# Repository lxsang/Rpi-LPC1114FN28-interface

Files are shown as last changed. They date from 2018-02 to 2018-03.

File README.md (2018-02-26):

# Rpi-LPC1114FN28-interface

This is a hobby project for an embedded application.  The point is that the Pi  is connected to a circuit based on the LPC1114FN28, in which, the ARM cortex M0 chip is used to collect sensor datas (IR sensor, sonar sensor, etc.) and control some motors using an IC controller. The Pi talks to the LPC1114FN28 via a serial connection (UART or SPI), and takes care of some high level calculations based on the datas provided by the LPC chip, it then can analyse the environment's context and send commands to the slave (ARM) chip for some control. For this prject, i decide to design my own PCB for the interface and write a firmware/middleware for  the interface.

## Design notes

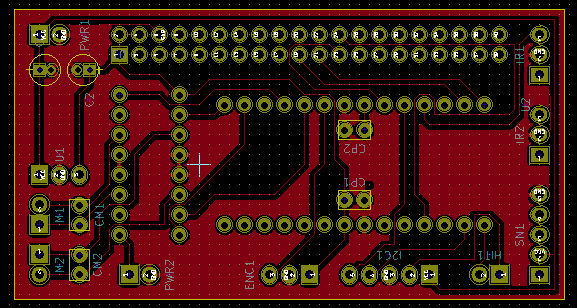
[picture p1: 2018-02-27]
schematic/images/pcb-front.png

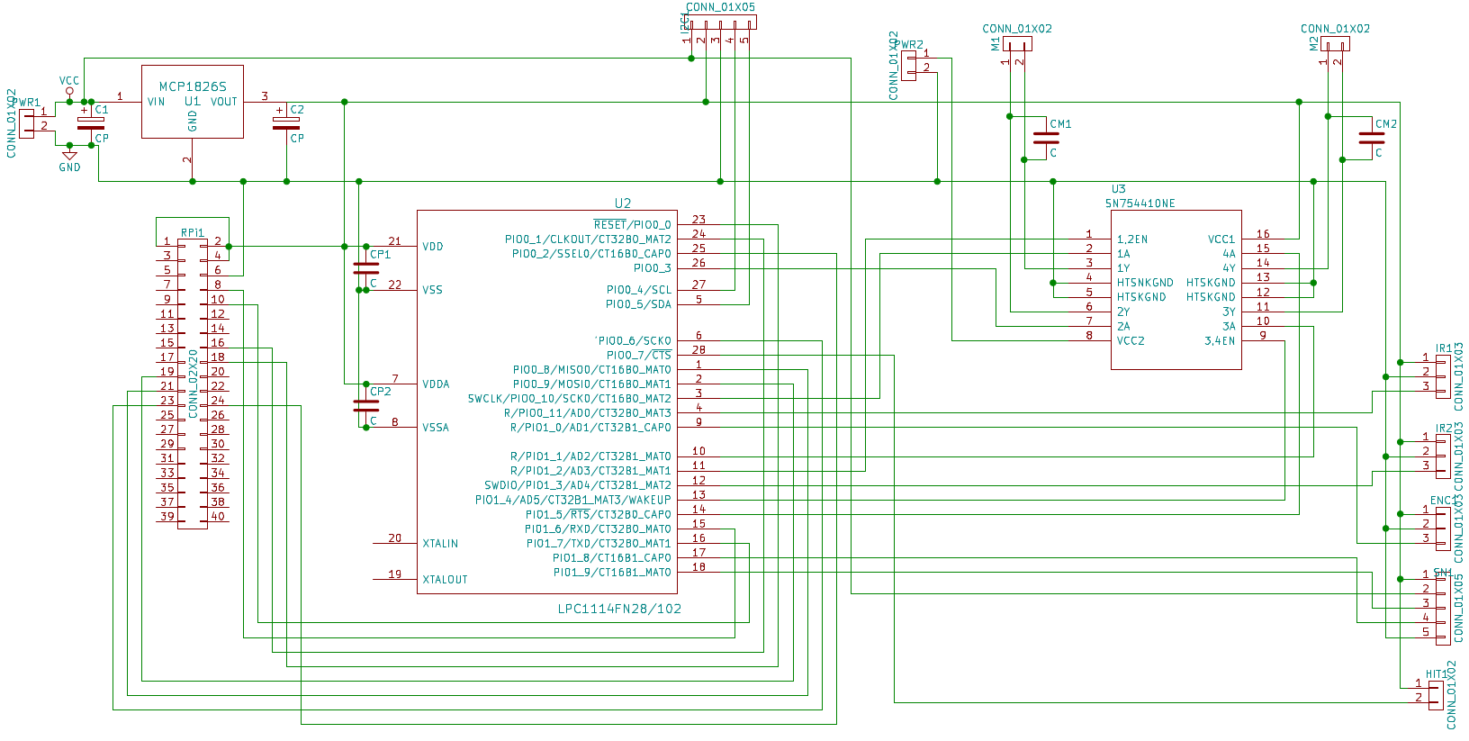
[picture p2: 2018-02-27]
schematic/images/schematic.png

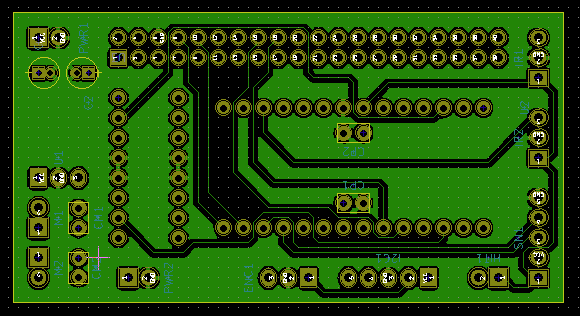
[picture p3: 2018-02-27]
schematic/images/pcb-back.png

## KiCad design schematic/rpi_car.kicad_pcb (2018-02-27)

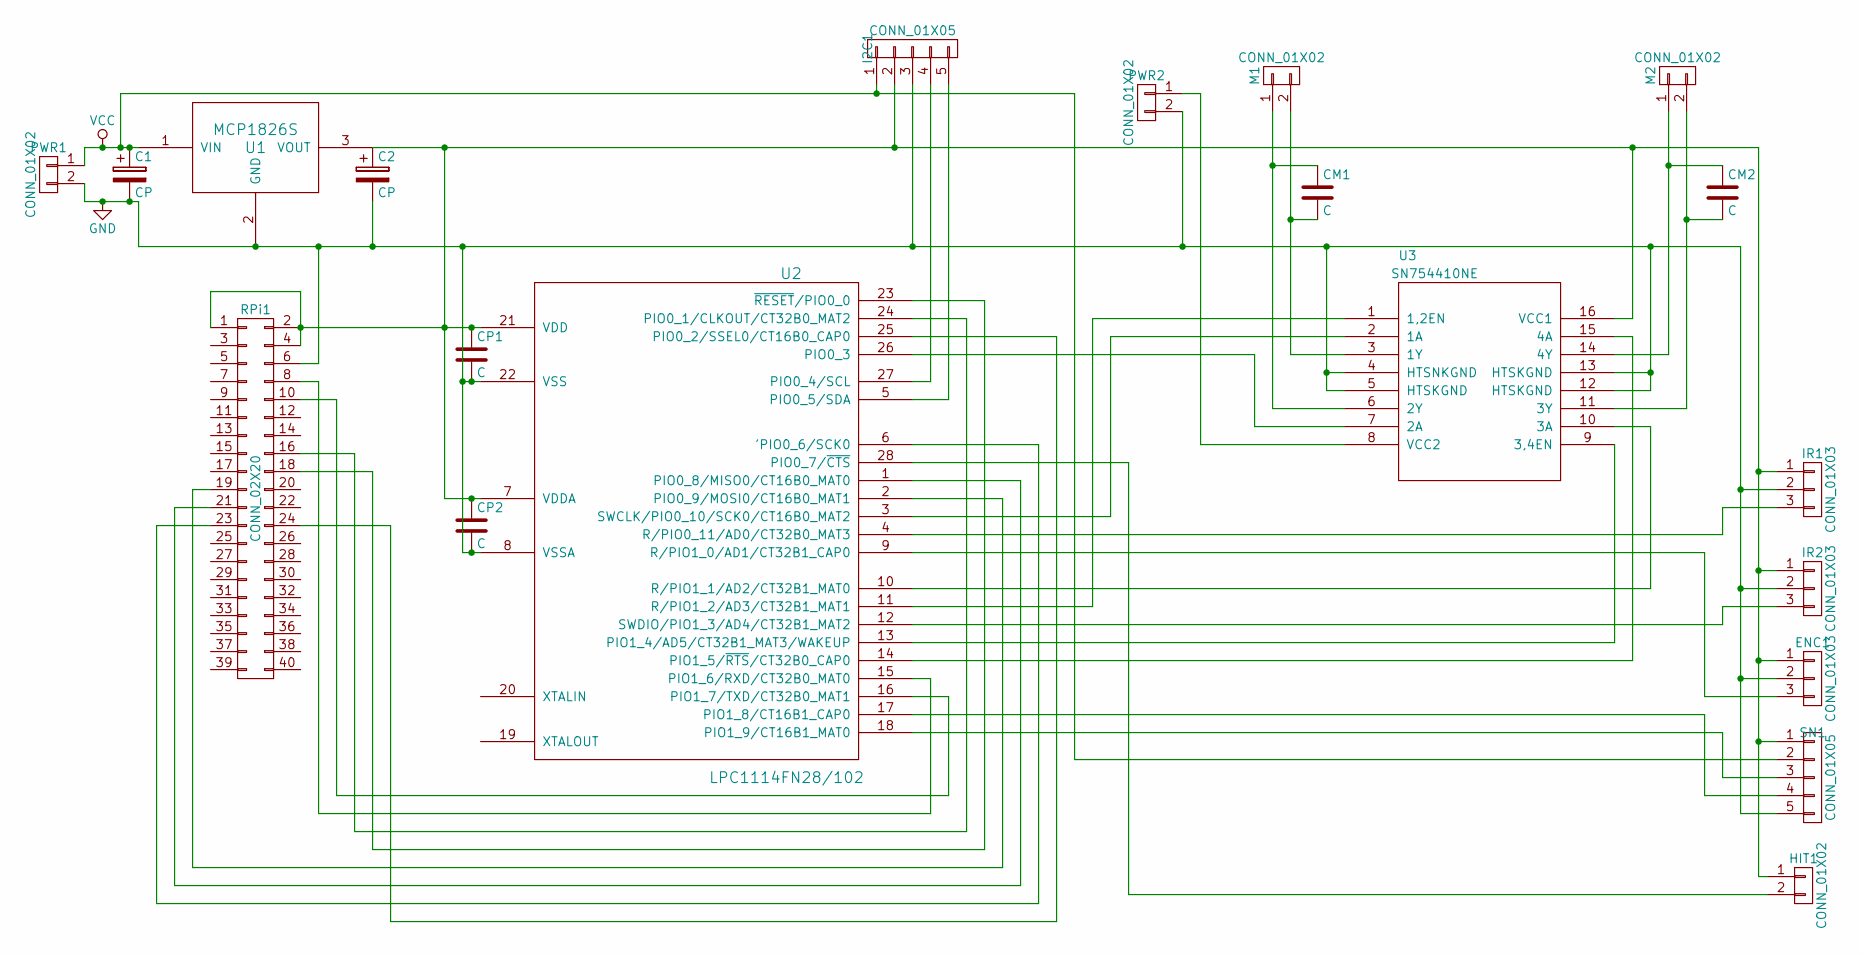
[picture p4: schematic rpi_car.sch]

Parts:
C1, C2: CP; CP_Radial_D4.0mm_P1.50mm
CM1, CM2: C; C_Rect_L4.0mm_W2.5mm_P2.50mm
CP1, CP2: C; C_Rect_L4.0mm_W2.5mm_P2.50mm
ENC1: CONN_01X03; Pin_Header_Straight_1x03
HIT1: CONN_01X02; Pin_Header_Straight_1x02
I2C1: CONN_01X05; Pin_Header_Straight_1x05
IR1, IR2: CONN_01X03; Pin_Header_Straight_1x03
M1, M2: CONN_01X02; Pin_Header_Straight_1x02
PWR1, PWR2: CONN_01X02; Pin_Header_Straight_1x02
RPi1: CONN_02X20; Pin_Header_Straight_2x20
SN1: CONN_01X05; Pin_Header_Straight_1x05
U1: MCP1826S; Pin_Header_Straight_1x03
U2: LPC1114FN28/102; DIP-28_W15.24mm
U3: SN754410NE; DIP-16_W7.62mm

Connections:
GND: C1.2, C2.2, CP1.2, CP2.2, ENC1.2, I2C1.3, IR1.2, IR2.2, PWR1.2, PWR2.2, RPi1.6, SN1.5, U1.2 (GND), U2.8 (VSSA), U2.22 (VSS), U3.4 (HTSNKGND), U3.5 (HTSKGND), U3.12 (HTSKGND), U3.13 (HTSKGND)
unnamed: C2.1, CP1.1, CP2.1, ENC1.1, HIT1.1, I2C1.2, IR1.1, IR2.1, RPi1.1, RPi1.2, RPi1.4, SN1.1, U1.3 (VOUT), U2.7 (VDDA), U2.21 (VDD), U3.16 (VCC1)
unnamed: CM1.1, M1.1, U3.6 (2Y)
unnamed: CM1.2, M1.2, U3.3 (1Y)
unnamed: CM2.1, M2.1, U3.14 (4Y)
unnamed: CM2.2, M2.2, U3.11 (3Y)
unnamed: ENC1.3, U2.9 (R/PIO1_0/AD1/CT32B1_CAP0)
unnamed: HIT1.2, U2.28 (PIO0_7/~CTS)
unnamed: I2C1.4, U2.27 (PIO0_4/SCL)
unnamed: I2C1.5, U2.5 (PIO0_5/SDA)
unnamed: IR1.3, U2.4 (R/PIO0_11/AD0/CT32B0_MAT3)
unnamed: IR2.3, U2.12 (SWDIO/PIO1_3/AD4/CT32B1_MAT2)
unnamed: PWR2.1, U3.8 (VCC2)
unnamed: RPi1.8, U2.15 (PIO1_6/RXD/CT32B0_MAT0)
unnamed: RPi1.10, U2.16 (PIO1_7/TXD/CT32B0_MAT1)
unnamed: RPi1.16, U2.24 (PIO0_1/CLKOUT/CT32B0_MAT2)
unnamed: RPi1.18, U2.23 (~RESET~/PIO0_0)
unnamed: RPi1.19, U2.2 (PIO0_9/MOSI0/CT16B0_MAT1)
unnamed: RPi1.21, U2.1 (PIO0_8/MISO0/CT16B0_MAT0)
unnamed: RPi1.23, U2.6 ('PIO0_6/SCK0)
unnamed: RPi1.24, U2.25 (PIO0_2/SSEL0/CT16B0_CAP0)
unnamed: SN1.3, U2.18 (PIO1_9/CT16B1_MAT0)
unnamed: SN1.4, U2.17 (PIO1_8/CT16B1_CAP0)
unnamed: U2.3 (SWCLK/PIO0_10/SCK0/CT16B0_MAT2), U3.2 (1A)
unnamed: U2.10 (R/PIO1_1/AD2/CT32B1_MAT0), U3.10 (3A)
unnamed: U2.11 (R/PIO1_2/AD3/CT32B1_MAT1), U3.1 (1,2EN)
unnamed: U2.13 (PIO1_4/AD5/CT32B1_MAT3/WAKEUP), U3.9 (3,4EN)
unnamed: U2.14 (PIO1_5/~RTS~/CT32B0_CAP0), U3.15 (4A)
unnamed: U2.26 (PIO0_3), U3.7 (2A)
VCC: C1.1, I2C1.1, PWR1.1, SN1.2, U1.1 (VIN)

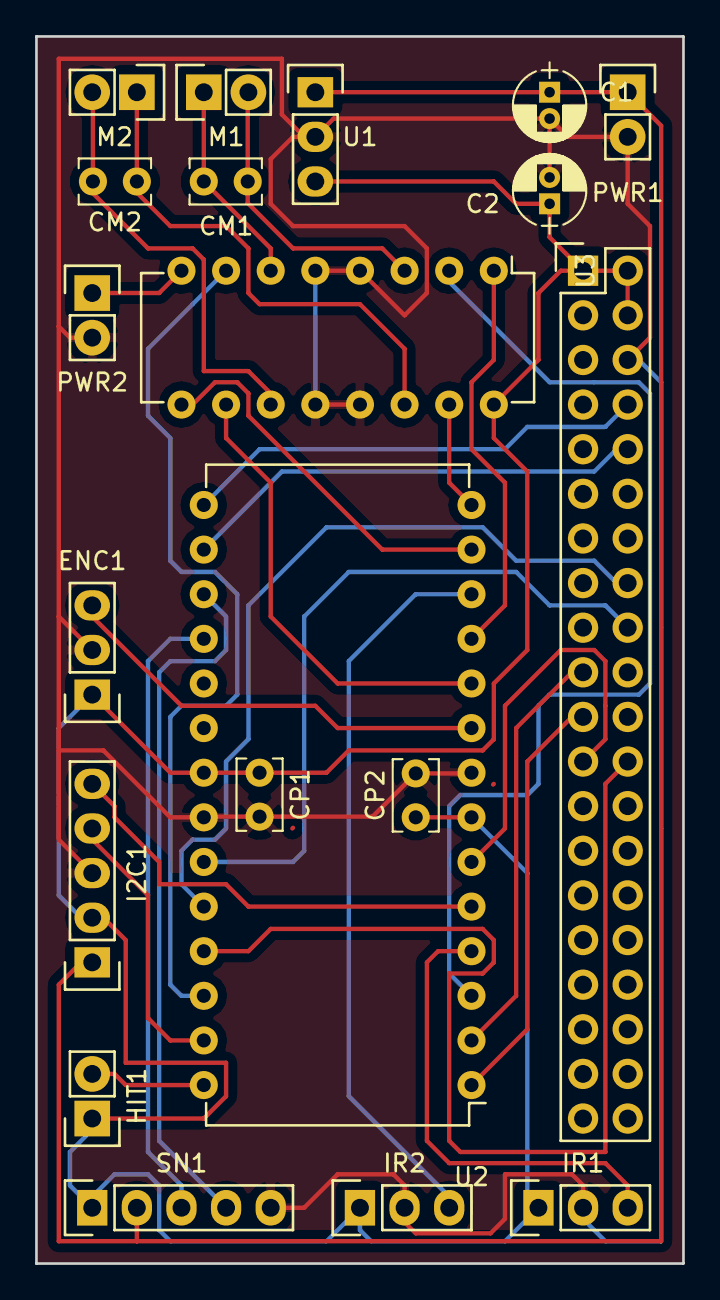
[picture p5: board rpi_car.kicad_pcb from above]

Board: 2 copper layers, 36.8 x 69.8 mm, 20 parts (0 on the bottom side), 30 nets.

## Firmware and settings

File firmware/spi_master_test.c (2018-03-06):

#include <stdint.h>
#include <unistd.h>
#include <stdio.h>
#include <stdlib.h>
#include <getopt.h>
#include <fcntl.h>
#include <sys/ioctl.h>
#include <linux/types.h>
#include <linux/spi/spidev.h>

#define ARRAY_SIZE(a) (sizeof(a) / sizeof((a)[0]))

static const char *device = "/dev/spidev0.0";
static uint8_t mode;
static uint8_t bits = 8;
static uint32_t speed = 500000;
static uint16_t delay = 110;

int spi_open()
{
    int ret;
    int fd = open(device, O_RDWR);
	if (fd < 0)
	{
		perror("can't open device \n");
		return -1;
	}
	/*
	 * spi mode
	 */
	ret = ioctl(fd, SPI_IOC_WR_MODE, &mode);
	if (ret == -1)
	{
	    perror("can't set spi mode \n");
	    return -1;
	}

	ret = ioctl(fd, SPI_IOC_RD_MODE, &mode);
	if (ret == -1)
	{
		perror("can't get spi mode \n");
		return -1;
	}
	/*
	 * bits per word
	 */
	ret = ioctl(fd, SPI_IOC_WR_BITS_PER_WORD, &bits);
	if (ret == -1)
	{
		perror("can't set bits per word \n");
		return -1;
	}

	ret = ioctl(fd, SPI_IOC_RD_BITS_PER_WORD, &bits);
	if (ret == -1)
	{
	    perror("can't get bits per word");
	    return -1;
	}
	/*
	 * max speed hz
	 */
	ret = ioctl(fd, SPI_IOC_WR_MAX_SPEED_HZ, &speed);
	if (ret == -1)
	{
	    perror("can't set max speed hz");
	    return -1;
	}
	ret = ioctl(fd, SPI_IOC_RD_MAX_SPEED_HZ, &speed);
	if (ret == -1)
	{
		perror("can't get max speed hz");
		return -1;
	}

	printf("spi mode: %d\n", mode);
	printf("bits per word: %d\n", bits);
	printf("max speed: %d Hz (%d KHz)\n", speed, speed/1000);
	
	return fd;
}

int spi_send_cmd(int fd, uint8_t cmd, uint8_t idx, uint8_t value)
{
    int ret;
    uint8_t tx[3]; 
    uint8_t rx[3] = {0, };
	struct spi_ioc_transfer tr = {
		.tx_buf = (unsigned long)tx,
		.rx_buf = (unsigned long)rx,
		.len = 3,
		.delay_usecs = delay,
		.speed_hz = speed,
		.bits_per_word = bits
	};
	tx[0] = cmd;
	tx[1] = idx;
	tx[2] = value;
	ret = ioctl(fd, SPI_IOC_MESSAGE(1), &tr);
    if (ret < 1)
    {
        perror("can't send spi message");
    	return -1;
    }
    //if(cmd == 255)
    // printf("RX %d %d %d \n", rx[0], rx[1], rx[2]);
    return (int) rx[0];
}

int spi_set(int fd,uint8_t idx, uint8_t v)
{
    return spi_send_cmd(fd,1, idx, v);
}

int spi_get(int fd,uint8_t idx)
{
    // send command
    int ret;
    ret = spi_send_cmd(fd,0,idx,0);
    if(ret == -1) return -1;
    // read back
    return spi_send_cmd(fd,255,255,255);
}

void spi_read_buff(int fd,uint8_t* buf, int size)
{
    int ret;
    uint8_t tx[size];
	struct spi_ioc_transfer tr = {
		.tx_buf = (unsigned long)tx,
		.rx_buf = (unsigned long)buf,
		.len = size,
		.delay_usecs = delay,
		.speed_hz = speed,
		.bits_per_word = bits
	};
	spi_send_cmd(fd,2,0,size);
	ret = ioctl(fd, SPI_IOC_MESSAGE(1), &tr);
    if (ret < 1)
    {
        perror("can't send spi message");
    	return;
    }
}

void spi_write_buff(int fd, uint8_t* buf, int size)
{
    int i;
    for(i=0; i < size; i++)
        spi_set(fd,i,buf[i]);
    
}

int main(int argc, char *argv[])
{
	int ret = 0;
	int fd;
	int _cmd;
	int _value;
	int _idx;
	
	if(argc != 3)
	{
	    printf("spi cmd value");
	}
    _idx = atoi(argv[1]);
    _value = atoi(argv[2]);
    
    fd = spi_open();
    
    if(fd == -1) return -1;
    printf("device is opened\n");
    
    uint8_t data[64];
    for(ret = 0; ret < 64; ret++)
        data[ret] = ret +1;
    
    //for(ret = 0)
    spi_write_buff(fd,data,64);
    
	spi_set(fd,_idx,_value);
	
	spi_read_buff(fd,data,64);
	
	for(ret = 0; ret < 64; ret ++)
	{
	    printf("%d ", data[ret]);
	    //data[ret] = ret+1;
	}
	printf("\n");
	
	//spi_write_buff(fd,data,8);
	close(fd);

	return 1;
}
